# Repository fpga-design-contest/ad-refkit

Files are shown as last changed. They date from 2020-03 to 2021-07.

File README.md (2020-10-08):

# ad-refkit-sample
A sample design of the reference kit for FPGA Design Competition about autonomous driving

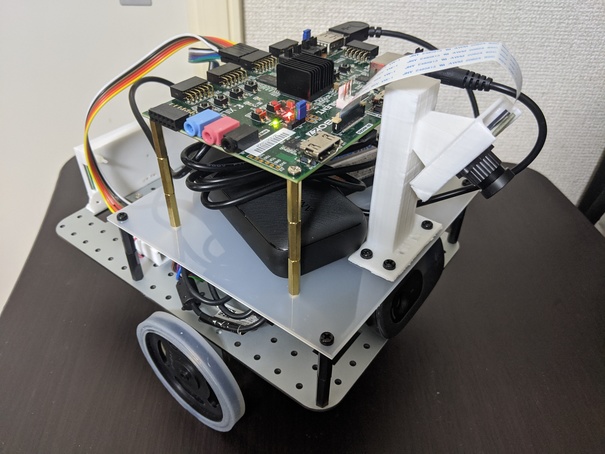
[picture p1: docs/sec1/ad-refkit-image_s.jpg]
ad-refkit


# Setup
See [documentations](./docs/README.md).

# Reference
- Yuya Kudo (Ritsumeikan U.), Atsushi Takada (Ritsumeikan U.), Yuta Ishida (Ritsumeikan U.), and Tomonori Izumi (Ritsumeikan U.), "An SoC-FPGA-Based Micro UGV with Localization and Motion Planning", Proc. 2019 International Conference on Field-Programmable Technology, pp.469-472, DOI 10.1109/ICFPT47387.2019.00095, Dec.2019.
- Yuya Kudo, Atsushi Takada, Soji Tsuda, Takumi Sakai, Tomonori Izumi, "A Platform on All-Programmable SoC for Micro Autonomous Robots", Proc. 2018 International Conference on Field-Programmable Technology, pp.406-409, DOI 10.1109/FPT.2018.00085, Dec.2018.

# Contest
http://fpt19.tju.edu.cn/Contest/FPT2019_FPGA_Design_Competition.htm

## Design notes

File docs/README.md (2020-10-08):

# ad-refkit

1. [Refkit Body](./sec1/index.md)
1. [Building Hardware Design](./sec2/index.md)
1. [Building Linux](./sec3/index.md) optional, prebuilt files are available.
1. [Prepare microSD](./sec4/index.md)
1. [Run Application](./sec5/index.md)

ad-refkit
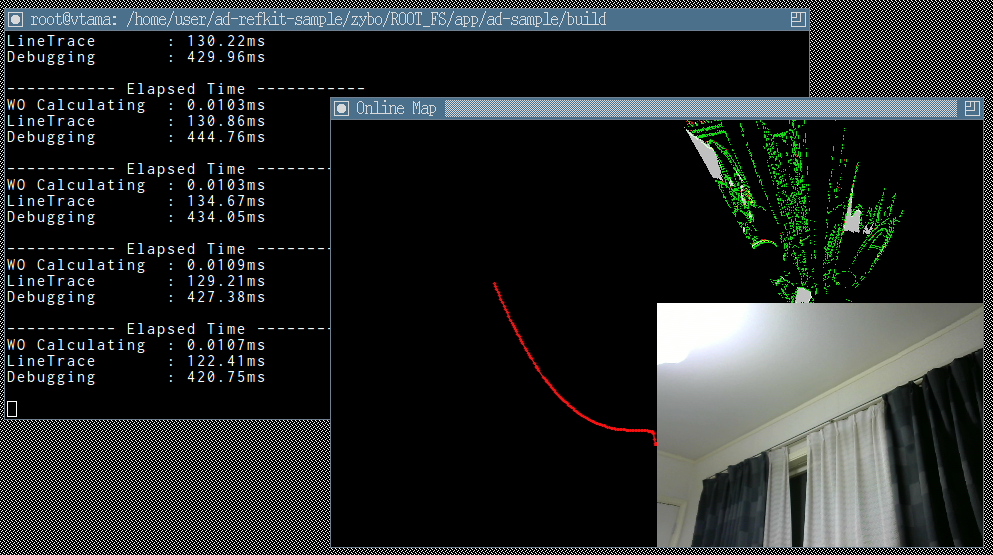
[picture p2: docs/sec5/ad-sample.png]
ad-refkit ad-sample


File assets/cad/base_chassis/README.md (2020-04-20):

# base chassis

ref. http://www.ritsumei.ac.jp/se/re/izumilab/lecture/16zybot/zybotr_base.pdf

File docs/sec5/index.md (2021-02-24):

## Run application
Connect ZYBO Z7-20 and host computer with Ethernet cable and USB cable.\
And then, insert microSD card into ZYBO Z7-20 and turn on the power switch.\
Access to ZYBO Z7-20 via USB tty and assign a IP-address to eth0.

### Setup
Set IP-address on ZYBO Z7-20:

``` sh
# ip addr add <IP ADDRESS> dev eth0 # ex. ip addr add 192.168.2.100/24 dev eth0
```

After that, transfer all of the files in `zybo/ROOT_FS` into `/root` on ZYBO Z7-20.

``` sh
$ scp -r <ROOT OF THIS REPOSITORY>/zybo/ROOT_FS/* root@<IP ADDRESS>:/root
```

### Login and setup kernel-modules and headers

Login to Z7-20 as root by SSH.

``` sh
$ ssh -X root@<IP ADDRESS>
```

In case that your ZYBO Z7-20 cannot connect the Internet, set date by your hand.

```
# date -s "10 JUL 2020 19:40:00" # an example
```

At your first login, run the following commands to install Debian packages.

``` sh
$ cd ~/package
$ dpkg -i linux-image-4.19.0-xilinx_4.19.0-xilinx-4_armhf.deb
$ dpkg -i linux-headers-4.19.0-xilinx_4.19.0-xilinx-4_armhf.deb
$ dpkg -i linux-libc-dev_4.19.0-xilinx-4_armhf.deb
```

### Setup WiFi (if necessary)

Compile the driver on ZYBO Z7-20:

```
# cd /root/rtl8188eu
# git checkout v5.2.2.4
# make
# make install
```

After building and installation of the driver, the dirver module will be loaded at the WiFi adapter connected as the following.

```
# lsmod 
Module                  Size  Used by
8188eu               1392640  0
v4l2                   32768  0
sha256_generic         20480  0
cfg80211              249856  1 8188eu
```

You can find your adapter by `iwconfig`.

```
# iwconfig 
eth0      no wireless extensions.

lo        no wireless extensions.

sit0      no wireless extensions.

wlxd037451c9c81  IEEE 802.11  ESSID:off/any  
          Mode:Managed  Access Point: Not-Associated   Tx-Power=12 dBm   
          Retry short limit:7   RTS thr:off   Fragment thr:off
          Encryption key:off
          Power Management:on
```

You can make a setup of WiFi connection by the following instructions.

1. Generate `wpa_supplicant.conf` (only first time to connect the target SSID)

```
# wpa_passphrase <YOUR SSID> <YOUR PASSWORD> > /etc/wpa_supplicant/wpa_supplicant.conf
```

2. Add some parameters in `/etc/wpa_supplicant/wpa_supplicant.conf` (only first time to connect the target SSID)

```
        proto=RSN
        key_mgmt=WPA-PSK
        pairwise=CCMP
        group=CCMP
```

3. Connect WiFi access point and get IP-address

```
# wpa_supplicant -iwlxd037451c9c81 -c/etc/wpa_supplicant/wpa_supplicant.conf &
# dhclient wlxd037451c9c81
```

The WiFi modules work well are Buffalo WLI-UC-GNM, PLANEX GW-USValue-EZ, TP-Link TL-WN725N, and Elecom WDC-150SU2MBK.

### Before running applictions

Execute `init.sh`.
Executing this script is necessary every time before running ad-refkit applications.

``` sh
$ sh init.sh
```
For Experimantal Vivado 2020.1 support, please execute init20201.sh instead.

### ad-sample

``` sh
$ cd <ROOT OF THIS REPOSITORY>/zybo/ROOT_FS/app/ad-sample
$ export AD_SAMPLE_ROOT=$(pwd)
$ mkdir build && cd build
$ cmake ..
$ make
$ ./ad-sample
```

ad-sample

(sorry, this example picture is case not running on the course)

### make-calibration-param
(You should see in this process in [ad-refkit calibration](https://docs.google.com/presentation/d/18L2UL7cB7N1HqGs9Y_z4J0kfmSX4V-YpADnjRLmr1OU/edit#slide=id.p) (sorry written in Japanese))

Execute camera calibration by using OpenCV.
First of all, make `take-pcam-image` as the following.

``` sh
$ cd <ROOT OF THIS REPOSITORY>/zybo/ROOT_FS/app/take-pcam-image
$ mkdir build && cd build
$ cmake ..
$ make
```

And then, prepare image data by the following processes.

1. Print checkerboard (available on http://opencv.jp/sample/pics/chesspattern_7x10.pdf)
2. Take about 30 pictures of the checkerboard from various angles by using the calibration target camera with built `take-pcam-image`.
    - Take pictures of whole of checkerboard.
    - Save pictures in a directory.
    - The extension of the files should be png (as the application default).
    - The name of the files should be `img<#>.png` (as the application default).
    - `<#>` should be series numbers from `0` (as the application default).

After preparing picture files, start calibration.

``` sh
$ cd <ROOT OF THIS REPOSITORY>/zybo/ROOT_FS/app/make-calibration-param
$ mkdir build && cd build
$ cmake ..
$ make
$ ./make-calibration-param
```

The `make-calibration-param` execution should be like the following.

```
$ cd app/take-pcam-image
$ mkdir build
$ cmake ..
$ make
$ ./make-calibration-param 
Please input a path where you saved checkerboard images : ../data/
Please input the number of image : 30
Please input the number of checker board column : 10
Please input the number of checker board row : 7
Please input squares size (mm) : 23
…
```

The program displays pictures, enter some key to progress the operation.

After executing the program, you can get `calib_param.xml` in the directory. You should copy the generated `calib_param.xml` into apropreate directries.

```
$ cp calib_param.xml ../../pcam-test/data/pcam_calibration_parameter.xml
$ cp calib_param.xml ../../ad-sample/data/HWController/pcam_calibration_parameter.xml
```

### make-homography-param
(You should see in this process in [ad-refkit calibration](https://docs.google.com/presentation/d/18L2UL7cB7N1HqGs9Y_z4J0kfmSX4V-YpADnjRLmr1OU/edit#slide=id.p) (sorry written in Japanese))

Calculate the projection transformation matrix required to obtain a bird's eye view
of the road surface in front of car.
First of all, prepare image data by the follow steps.

1. Prepare a square of paper or a thin board
2. Place the prepared paper or a thin board on the floor in front of the front of the vehicle.
3. Take a picture of the paper or the board by using `take-pcam-image`

After preparing image data, run the follow program.

``` sh
$ python3 make-homography-param.py
```

The program should be execucted as below.

```
$ cd app/make-homography-param
$ python3 make-homography-param.py 
Please input a corrected image path from Pcam5C that has not been transformed.
Note that an image should be included a square pattern on the ground.
>> img2-0.png
Click on the square vertices in the image in the order shown below:
1. Top Left
2. Bottom Left
3. Top Right
4. Bottom Right
(385, 379)
(280, 638)
(790, 376)
(883, 634)
Please choose menu shown below:
'c': Specify ratio and Y-axis offset
'q': Quit and Show the homography matrix
```

Click on the corners of the square and specify the magnification and offset to output the projection transformation matrix.

```
Homography Matrix:
[ 0.154904608011 , -0.075484258313 , 62.9015488835 
 -0.00132486853534 , 0.0190262314547 , 104.989571058 
 -4.64648773206e-07 , -0.000125816562256 , 0.276168644843 ]
```

Copy the output matrix into `app/ad-sample/data/HWController/param.yaml` and `app/pcam-test/src/main.cpp`

### motor-test
This program checks the behavior of motors.

``` sh
$ cd <ROOT OF THIS REPOSITORY>/zybo/ROOT_FS/app/motor-test
$ mkdir build && cd build
$ cmake ..
$ make
$ ./motor-test
```

### pcam-test
This program checks the behavior of Pcam5C.

``` sh
$ cd <ROOT OF THIS REPOSITORY>/zybo/ROOT_FS/app/pcam-test
$ mkdir build && cd build
$ cmake ..
$ make
$ ./pcam-test
```

### webcam-test
This program checks the behavior of Web camera working.

``` sh
$ cd <ROOT OF THIS REPOSITORY>/zybo/ROOT_FS/app/webcam-test
$ mkdir build && cd build
$ cmake ..
$ make
$ ./webcam-test
```

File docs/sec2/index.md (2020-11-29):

# Hardware Design
This flow generates a sample IP-block, bit-stream for ZYBO Z7-20, and BSP for the generated HW.

## Requirements
- Host PC, installed Ubuntu 18.04
- Vivado 2019.1
- [Digilent board files](https://github.com/Digilent/vivado-boards)
- A license for MIPI CSI controller from [MIPI CSI Controller Subsystems](https://www.xilinx.com/products/intellectual-property/ef-di-mipi-csi-rx.html) This license is already included in your Vivado license if you obtained your Webpack license from January 2020, the following step might be required if you have the older Webpack license:
  - Access to [Product Licensing](http://www.xilinx.com/getlicense)
  - Click "Search Now"
  - Type "MIPI CSI" in "Search:" text field
  - Select "LogiCORE, MIPI CSI-2 Rx Controller, Evaluation License" and Click "Add" button
  - Find "LogiCORE, MIPI CSI-2 Rx Controller, Evaluation License", click checkbox of that, and click "Generate Node-Locked License"
  - Fill required license and you can get an evaluation license of MIPI CSI controller.

## Build Flow
Run the following script to generate hardware design. Make sure Vivado is in your path by sourcing the `settings64.sh` in Vivado's directory. 

``` sh
$ cd <ROOT OF THIS REPOSITORY>/zybo/vivado/script
$ export AD_REFKIT_SAMPLE_SCRIPT_PATH=$(pwd)
$ sh setup_bd.sh
```

The script starts Vivado HLS and Vivado to generate IP-block and bit-file. The working directory is `$AD_REFKIT_SAMPLE_SCRIPT_PATH/../prj` .
After running Vivado, the script generates `fpga.bin` in `<ROOT OF THIS REPOSITORY>/ROOT_FS/firmware`, which is a configuration file for dynamic reconfiguration of ZYBO Z7-20. Please follow the board manual on how to program the FPGA using the generated bit file.
The script also generates BSP for software development in `<ROOT OF THIS REPOSITORY>/zybo/ROOT_FS/zynq_bsp/`.

## Experimental Build Flow with Vivado 2020.1
Starting from Vivado 2020.1, the Xilinx XSDK is replaced with a new development platform called Vitis. The Vitis API is different compared to the old XSDK. Also, the MIPI CSI IP which is used in this project is updated. Therefore, we provide a different build script for Vivado 2020.1 platform. Once the project is initiated for Vivado 2020.1, it will not be able to be opened in older Vivado version.
The bit stream format of 2020.1 version also changes as the fpga-bit2bin.py script can no longer convert the bitstream into a proper bin file. The included bootgen from vivado does the trick. However, this change also requires a lot of other changes on the subsequent software build process as the new bin format cannot be recognized by the fpga_manager built into old Xilinx kernel. Newer format requires newer kernel from Xilinx repository and upgrading Linux kernel requires adjustment on the drivers and a lot of other things.
This build flow is experimantal and seems to be sensitive to the gcc version installed in the host PC among other things. Please run the following script if you would like to try.

``` sh
$ cd <ROOT OF THIS REPOSITORY>/zybo/vivado/script
$ export AD_REFKIT_SAMPLE_SCRIPT_PATH=$(pwd)
$ sh setup_bd_20201.sh
```

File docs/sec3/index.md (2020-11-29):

## Building Linux
This step is optional. The generated files by this flow are available in this repository.
The required files are as follows:
- [uImage](../../zybo/BOOT_FS/uImage)
- [zynq-zybo-z7.dtb](../../zybo/BOOT_FS/zynq-zybo-z7.dtb)
- [Debian packages (headers, image, libc)](../../zybo/ROOT_FS/package/)

If you want to build the Linux kernel on your computer, please run the followings:
``` sh
$ apt install build-essential ccache bc bison flex ncurses-dev git u-boot-tools gcc-arm*
$ git clone --depth 1 -b xilinx-v2019.1 https://github.com/Xilinx/linux-xlnx.git linux-xlnx-v2019.1-zybo-z7 && cd linux-xlnx-v2019.1-zybo-z7
$ git checkout -b linux-xlnx-v2019.1-zybo-z7 refs/tags/xilinx-v2019.1
$ sed -i -e 's|bootargs = ""|bootargs = "console=ttyPS0,115200 root=/dev/mmcblk0p2 rw earlyprintk rootfstype=ext4 rootwait devtmpfs.mount=1 uio_pdrv_genirq.of_id=generic-uio earlycon"|g' arch/arm/boot/dts/zynq-zybo-z7.dts
$ patch -p1 < <ROOT OF THIS REPOSITORY>/assets/patch/linux-xlnx-v2019.1-zybo-z7-builddeb.diff
$ git add --update
$ git commit -m "update dts for zybo-z7"
$ git tag -a xilinx-v2019.1-zybo-z7-3 -m "release xilinx-v2019.1-zybo-z7-3"
$ echo 3 > .version
$ make xilinx_zynq_defconfig ARCH=arm CROSS_COMPILE=arm-linux-gnueabihf-
$ patch -p0 < <ROOT OF THIS REPOSITORY>/assets/patch/dot.config.patch
$ ccache make -j<some number> deb-pkg ARCH=arm CROSS_COMPILE=arm-linux-gnueabihf- DTC_FLAGS=--symbols
$ make uImage ARCH=arm CROSS_COMPILE=arm-linux-gnueabihf- UIMAGE_LOADADDR=0x8000
$ cp arch/arm/boot/uImage <ROOT OF THIS REPOSITORY>/zybo/BOOT_FS
$ cp arch/arm/boot/dts/zynq-zybo-z7.dtb <ROOT OF THIS REPOSITORY>/zybo/BOOT_FS
$ cp ../linux-*.deb <ROOT OF THIS REPOSITORY>/zybo/ROOT_FS/package
```
A shell script to automate this process is provided for your convenience. Install the requirements then run the provided script. Make sure `AD_REFKIT_SAMPLE_SCRIPT_PATH` is set as instructed in the previous step.
``` sh
$ sudo apt install build-essential ccache bc bison flex ncurses-dev git u-boot-tools gcc-arm*
$ sh build_linux.sh
```
For the experimental Vivado 2020.1 support, you can skip this process as the Linux build process is integrated into the ROOT FS build flow.

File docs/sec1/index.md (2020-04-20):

## ad-refkit body

ad-refkit

### Requirements

| Item | Qty. | Vendor | Remark |
|---|:----:|:---:|---|
| ZYBO Z7-20 | 1 | Digilent | https://store.digilentinc.com/zybo-z7-zynq-7000-arm-fpga-soc-development-board/ |
| Motor | 2 | Digilent | https://store.digilentinc.com/dc-motor-gearbox-1-53-gear-ratio-custom-6v-motor-designed-for-digilent-robot-kits/ |
| Tire and Wheel | 2 | Digilent | https://store.digilentinc.com/wheel-kit-d-slot-pair-abs-injection-molded-wheels-compatible-with-digilent-motor-mounts-limited-time/ |
| Tail Skid | 1 | Digilent | https://store.digilentinc.com/tail-skid-limited-time/ |
| Pcam5C | 1 | Digilent | https://reference.digilentinc.com/reference/add-ons/pcam-5c/start |
| Pmod HB5 | 2 | Digilent | https://store.digilentinc.com/pmod-hb5-h-bridge-driver-with-feedback-inputs/ |
| Motor mounter | 1 | Digilent | https://store.digilentinc.com/double-motor-mount-metal-mount-to-affix-a-pair-of-digilent-motors-limited-time/ |
| Mobile Battery (PowerCore 10000 PD Redux) | 1 | Anker | https://www.ankerjapan.com/category/COMPACT/A1239.html |
| Web camera | 1 | | |
|  - ex. BSW20KM11BK | | iBUFFALO | https://www.buffalo.jp/product/series/BSW20KM11BK |
|  - ex. Logicool C270 | | Logicool | https://www.logitech.com/en-us/product/hd-webcam-c270 |
| USB Hub | 1 | | https://www.sanwa.co.jp/product/syohin.asp?code=USB-HTV410BKN |
|  - ex. USB-HTV410BKN | | SANWASUPPLY | https://www.sanwa.co.jp/product/syohin.asp?code=USB-HTV410BKN |
|  - ex. U2H-TZ427SBK | | Elecom | https://www.elecom.co.jp/products/U2H-TZ427SBK.html |
| Debug console (character display) | 1 | | |
|  - ex. Kyoritsu OLED display module | | KYOHRITSU | https://eleshop.jp/shop/g/gC9B362/ |
|  - ex. Akizuki OLED display module | | Akizuki | http://akizukidenshi.com/catalog/g/gP-08277/ |
| micro SD | 1 | - | more than 8GB |
| USB Type-A to DC-jack | 1 | | |
|  - ex. BENSN 10 in 1 | | | https://www.amazon.co.jp/gp/product/B07Y5DCBRL/ |
| Battery holder for 4xAAA | 1 | | |
| Base chassis | 1 | - | [STEP](../../assets/cad/base_chassis/robocar_base2.step) |
| Middle layer chassis | 1 | - | |
| Pcam5C mounter | 1 | - | [STL](../../assets/cad/Pcam5C/Pcam5C_mounter.stl) |
| OLED holder | 1 | - | [STL](../../assets/cad/OLED_holder/OLED_holder.stl) |
| HB5 holder | 2 | - | [STL](../../assets/cad/HB5_holder/HB5_holder.stl) |
| spacers, screws, nuts, washers | | | |
| wires | | | |
| Self Adhesive magnetic tape | | | |

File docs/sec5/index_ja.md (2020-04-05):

## アプリケーションの実行
イーサネットケーブルを用意し、ZYBOのイーサネットポートに差し込みます。\
ケーブルをホストPCと同一セグメントに存在するDHCP機能を持つルータに接続した後、
作成したMicroSDカードをZYBO Z7-20にセットし、電源を投入してください。\
UARTのシリアルコンソールからログインし、DHCPにより割り振られたIPアドレスを確認します。

``` sh
$ ip address show
```

IPアドレスが確認出来たら、
`zybo/ROOT_FS`下のすべてのファイルをZYBOで動作するUbuntu上の`/root`下に転送してください。

``` sh
$ scp -r <ROOT OF THIS REPOSITORY>/zybo/ROOT_FS/* root@<ZYBOのIPアドレス>:/root
```

SSHでrootログインします。

``` sh
$ ssh -X root@<ZYBOのIPアドレス>
```

最初の一度だけパッケージのインストールを行う必要があります。

``` sh
$ cd ~/package
$ dpkg -i linux-image-4.19.0-xilinx_4.19.0-xilinx-4_armhf.deb
$ dpkg -i linux-headers-4.19.0-xilinx_4.19.0-xilinx-4_armhf.deb
$ dpkg -i linux-libc-dev_4.19.0-xilinx-4_armhf.deb
```

次に`init.sh`を実行して下さい。
これは**ZYBOを起動する度**に実行する必要があります。

``` sh
$ sh init.sh
```

以上でアプリケーションの実行が可能になります。

### ad-sample
NOTE: 動作未確認

``` sh
$ cd <ROOT OF THIS REPOSITORY>/zybo/ROOT_FS/app/ad-sample
$ export AD_SAMPLE_ROOT=$(pwd)
$ mkdir build && cd build
$ cmake ..
$ make
$ ./ad-sample
```

### make-calibration-param
NOTE: 動作未確認

OpenCVを用いたカメラキャリブレーションを実行します。\
はじめに、以下の手順に従って画像データを用意して下さい。

1. チェッカーボードを印刷する
2. キャリブレーションを行うカメラでチェッカーボードを様々な角度から30枚程度撮影する
    - チェッカーボード全体が映るように撮影してください
    - 画像ファイルは同一ディレクトリ下に保存してください
    - png形式で保存して下さい
    - ファイル名は`img<番号>.png`としてください
    - `<番号>`は`0`から始まる連番にしてください

画像データが用意できたらキャリブレーションを実行します。

``` sh
$ cd <ROOT OF THIS REPOSITORY>/zybo/ROOT_FS/app/make-calibration-param
$ mkdir build && cd build
$ cmake ..
$ make
$ ./make-calibration-param
```

### make-homography-param
前方の路面の俯瞰画像を得る際に必要な射影変換行列を導出します。\
はじめに、以下の手順に従って画像データを用意して下さい。

1. 正方形の紙、もしくは、薄い板を用意する
2. 用意した紙、もしくは、薄い板を車体の前方正面の床面に設置する
3. 撮影する

画像データが用意できたらプログラムを実行します。

``` sh
$ python3 make-homography-param.py
```

正方形の四隅をクリックし、倍率、オフセットを指定すると射影変換行列が出力されます。

### motor-test
モータの動作を確認することが出来ます。

``` sh
$ cd <ROOT OF THIS REPOSITORY>/zybo/ROOT_FS/app/motor-test
$ mkdir build && cd build
$ cmake ..
$ make
$ ./motor-test
```

### pcam-test
NOTE: 動作未確認

``` sh
$ cd <ROOT OF THIS REPOSITORY>/zybo/ROOT_FS/app/pcam-test
$ mkdir build && cd build
$ cmake ..
$ make
$ ./pcam-test
```

### webcam-test
NOTE: 動作未確認

``` sh
$ cd <ROOT OF THIS REPOSITORY>/zybo/ROOT_FS/app/webcam-test
$ mkdir build && cd build
$ cmake ..
$ make
$ ./webcam-test
```

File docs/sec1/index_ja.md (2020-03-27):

## 車体の構築
TODO: 車体のディテールを固める

### 必要な部品

| 名称 | 数量 | メーカー | 備考 |
|---|:----:|:---:|---|
| ZYBO Z7-20 | 1 | Digilent | https://store.digilentinc.com/zybo-z7-zynq-7000-arm-fpga-soc-development-board/ |
| モーター | 2 | Digilent | https://store.digilentinc.com/dc-motor-gearbox-1-53-gear-ratio-custom-6v-motor-designed-for-digilent-robot-kits/ |
| 車輪 | 2 | Digilent | https://store.digilentinc.com/wheel-kit-d-slot-pair-abs-injection-molded-wheels-compatible-with-digilent-motor-mounts-limited-time/ |
| タイヤ | 2 | Digilent | https://store.digilentinc.com/wheel-kit-d-slot-pair-abs-injection-molded-wheels-compatible-with-digilent-motor-mounts-limited-time/ |
| キャスター | 1 | Digilent | https://store.digilentinc.com/tail-skid-limited-time/ |
| モバイルバッテリー(PowerCore+ 26800 PD) | 1 | Anker | https://www.ankerjapan.com/item/B1375.html |
| Pcam | 1 | Digilent | https://reference.digilentinc.com/reference/add-ons/pcam-5c/start |
| Webカメラ(BSW20KM11BK) | 1 | iBUFFALO | https://www.buffalo.jp/product/series/BSW20KM11BK |
| USBハブ | 1 | SANWASUPPLY | https://www.sanwa.co.jp/product/syohin.asp?code=USB-HTV410BKN |
| Pmod HB5 | 2 | Digilent | https://store.digilentinc.com/pmod-hb5-h-bridge-driver-with-feedback-inputs/ |
| 車輪モータマウント | 1 | Digilent | https://store.digilentinc.com/double-motor-mount-metal-mount-to-affix-a-pair-of-digilent-motors-limited-time/ |
| OLEDディスプレイモジュール | 1 | KYOHRITSU | https://eleshop.jp/shop/g/gC9B362/ |
| micro SD | 1 | - | 8GB以上推奨 |
| プラスチック板 | 2 | - | - |
| スペーサー 3cm | 2 | - | - |
| スペーサー 5cm | 2 | - | - |
| スペーサー 6cm | 4 | - | - |
| ネジ | - | - | - |
| ワッシャー | - | - | - |
| ナット | - | - | - |
| USB typeA to DCプラグ | 2 | - | ZYBO給電用とUSBハブ給電用 外径3.5mm |

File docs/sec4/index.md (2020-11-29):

## Prepare microSD
### 1. Format the MicroSD Card
Make partition with GParted. \
If you do not have GParted installed yet, please install it. Also, debootstrap is required to create a basic debian filesystem on the MicroSD.

``` sh
$ sudo apt install gparted debootstrap 
```

Run GParted, and then make two partitions on the MicroSD as follows:

``` sh
$ sudo gparted
```

- 1st partition : fat16, about 64-128MiB
- 2nd partition : ext4, all of rest

Pay attention to your MicroSD location (`/dev/sdX`) with X denoting your MicroSD location. Be careful not to use another drive.

### 2. Prepare rootfs
The next step is building the debian root filesystem for the FPGA board. There are two ways to achieve this: building the entire filesystem on host PC, then copy the resulting files to the MicroSD, or mount the MicroSD and build the filesystem directly on the MicroSD. The latter is considerably slower than the former. As a third option, we can use the provided script to streamline the building process for your convenience.

To achieve this, we will create a new chroot-ed directory for the debootstrap to work, then set the architecture of the filesystem to ARM. QEMU will be used to run the chroot-ed ARM filesystem on your PC. As the debootstrap completes its task, we will then install and configure the system as well as compiling OpenCV. The OpenCV compilation might take few hours depending on your PC. 

#### Building rootfs directly on the MicroSD

```
# install Ubuntu 18.04 LTS and neessary packages
$ sudo mount /dev/<YOUR SD #2 partition> /mnt # ex. /dev/sdd2
$ sudo debootstrap --foreign --arch armhf bionic /mnt http://ports.ubuntu.com/
$ sudo apt install qemu-user-static
$ sudo cp /usr/bin/qemu-arm-static /mnt/usr/bin/
$ sudo chroot /mnt
I have no name!@ubuntu:# ./debootstrap/debootstrap --second-stage
I have no name!@ubuntu:# passwd
I have no name!@ubuntu:# su
root@ubuntu:# passwd
root@ubuntu:# apt install software-properties-common
root@ubuntu:# add-apt-repository universe && apt update
root@ubuntu:# adduser user
root@ubuntu:# apt install locales ssh chrony libusb-1.0-0-dev
root@ubuntu:# locale-gen en_US.UTF-8
root@ubuntu:# apt install git
root@ubuntu:# git clone -b v1.4.7 https://git.kernel.org/pub/scm/utils/dtc/dtc.git dtc && cd dtc
root@ubuntu:# apt install build-essential flex bison
root@ubuntu:# make && make HOME=/usr install-bin
root@ubuntu:# cd .. && rm -rf dtc
root@ubuntu:# sed -i -e 's/#PasswordAuthentication/PasswordAuthentication/g' /etc/ssh/sshd_config
root@ubuntu:# sed -i -e 's/#PermitRootLogin prohibit-password/PermitRootLogin yes/g' /etc/ssh/sshd_config
root@ubuntu:# sed -i -e 's/AcceptEnv/#AcceptEnv/g' /etc/ssh/sshd_config
root@ubuntu:# echo 'server <available NTP server> iburst' >> /etc/ntp.conf # For example, ntp1.jst.mfeed.ad.jp
root@ubuntu:# systemctl enable chrony
root@ubuntu:# cat <<EOT > /etc/systemd/network/eth0.network
              [Match]
              Name=eth0
              [Network]
              DHCP=ipv4
              EOT
root@ubuntu:# systemctl enable systemd-networkd

# install OpenCV 4.2.0
root@ubuntu:# apt install -y \
              build-essential cmake ccache git pkg-config libgtk-3-dev \
              libavcodec-dev libavformat-dev libswscale-dev libv4l-dev \
              libxvidcore-dev libx264-dev libjpeg-dev libpng-dev libtiff-dev \
              gfortran openexr libatlas-base-dev python3-dev python3-numpy \
              libtbb2 libtbb-dev libdc1394-22-dev
root@ubuntu:# mkdir opencv_build && cd opencv_build
root@ubuntu:# git clone --depth 1 https://github.com/opencv/opencv.git
root@ubuntu:# git clone --depth 1 https://github.com/opencv/opencv_contrib.git
root@ubuntu:# export OPENCV_BUILD_PATH=$(pwd)
root@ubuntu:# cd opencv && mkdir build && cd build
root@ubuntu:# cmake -D CMAKE_BUILD_TYPE=RELEASE \
                    -D CMAKE_INSTALL_PREFIX=/usr/local \
                    -D INSTALL_C_EXAMPLES=ON \
                    -D INSTALL_PYTHON_EXAMPLES=ON \
                    -D OPENCV_GENERATE_PKGCONFIG=ON \
                    -D OPENCV_EXTRA_MODULES_PATH=$(printenv OPENCV_BUILD_PATH)/opencv_contrib/modules \
                    -D BUILD_EXAMPLES=ON ..
root@ubuntu:# ccache make -j<some number> # 4-5 hours, depends on your environment
root@ubuntu:# make install
root@ubuntu:# pkg-config --modversion opencv4
root@ubuntu:# cd ../../../ && rm -rf opencv_build
root@ubuntu:# apt install -y wireless-tools rfkill wpasupplicant linux-firmware libssl-dev usbutils
root@ubuntu:# cd /root
root@ubuntu:# git clone https://github.com/lwfinger/rtl8188eu.git
root@ubuntu:# exit
I have no name!@ubuntu:# exit
$ sync; sync; sync
$ sudo umount /mnt
$ sudo eject /dev/<YOUR SD> /mnt # ex. /dev/sdd
```

#### Building rootfs on your host PC and copy the files to MicroSD

```
$ mkdir <WORKING DIRECTORY>; cd <WORKING DIRECTORY> # ~/microsd
$ export WORKDIR=$(pwd)
$ sudo debootstrap --foreign --arch armhf bionic $WORKDIR http://ports.ubuntu.com/ 
$ sudo apt install qemu-user-static
$ sudo cp /usr/bin/qemu-arm-static $WORKDIR/usr/bin/
$ sudo chroot $WORKDIR
I have no name!@ubuntu:# ./debootstrap/debootstrap --second-stage
I have no name!@ubuntu:# passwd
I have no name!@ubuntu:# su
root@ubuntu:# passwd
root@ubuntu:# apt install -y software-properties-common
root@ubuntu:# add-apt-repository universe && apt update
root@ubuntu:# adduser user
root@ubuntu:# apt install -y locales ssh chrony libusb-1.0-0-dev ntpdate bc
root@ubuntu:# locale-gen en_US.UTF-8
root@ubuntu:# apt install -y git
root@ubuntu:# git clone -b v1.4.7 https://git.kernel.org/pub/scm/utils/dtc/dtc.git dtc && cd dtc
root@ubuntu:# apt install -y build-essential flex bison
root@ubuntu:# make && make HOME=/usr install-bin
root@ubuntu:# cd .. && rm -rf dtc
root@ubuntu:# sed -i -e 's/#PasswordAuthentication/PasswordAuthentication/g' /etc/ssh/sshd_config
root@ubuntu:# sed -i -e 's/#PermitRootLogin prohibit-password/PermitRootLogin yes/g' /etc/ssh/sshd_config
root@ubuntu:# sed -i -e 's/AcceptEnv/#AcceptEnv/g' /etc/ssh/sshd_config
root@ubuntu:# echo 'server <available NTP server> iburst' >> /etc/ntp.conf # For example, ntp1.jst.mfeed.ad.jp
root@ubuntu:# systemctl enable chrony
root@ubuntu:# cat <<EOT > /etc/systemd/network/eth0.network
              [Match]
              Name=eth0
              [Network]
              DHCP=ipv4
              EOT
root@ubuntu:# systemctl enable systemd-networkd

# install OpenCV 4.2.0
root@ubuntu:# apt install -y \
              build-essential cmake ccache git pkg-config libgtk-3-dev \
              libavcodec-dev libavformat-dev libswscale-dev libv4l-dev \
              libxvidcore-dev libx264-dev libjpeg-dev libpng-dev libtiff-dev \
              gfortran openexr libatlas-base-dev python3-dev python3-numpy \
              libtbb2 libtbb-dev libdc1394-22-dev
root@ubuntu:# mkdir opencv_build && cd opencv_build
root@ubuntu:# git clone --depth 1 https://github.com/opencv/opencv.git
root@ubuntu:# git clone --depth 1 https://github.com/opencv/opencv_contrib.git
root@ubuntu:# export OPENCV_BUILD_PATH=$(pwd)
root@ubuntu:# cd opencv && mkdir build && cd build
root@ubuntu:# cmake -D CMAKE_BUILD_TYPE=RELEASE \
                    -D CMAKE_INSTALL_PREFIX=/usr/local \
                    -D INSTALL_C_EXAMPLES=ON \
                    -D INSTALL_PYTHON_EXAMPLES=ON \
                    -D OPENCV_GENERATE_PKGCONFIG=ON \
                    -D OPENCV_EXTRA_MODULES_PATH=$(printenv OPENCV_BUILD_PATH)/opencv_contrib/modules \
                    -D BUILD_EXAMPLES=ON ..
root@ubuntu:# ccache make -j<some number> # 2-3 hours, depends on your environment
root@ubuntu:# make install
root@ubuntu:# pkg-config --modversion opencv4
root@ubuntu:# cd ../../../ && rm -rf opencv_build
root@ubuntu:# apt install -y wireless-tools rfkill wpasupplicant linux-firmware libssl-dev usbutils
root@ubuntu:# cd /root
root@ubuntu:# git clone https://github.com/lwfinger/rtl8188eu.git
root@ubuntu:# exit
I have no name!@ubuntu:# exit
$ sudo mount /dev/<YOUR SD #2 partition> /mnt # ex. /dev/sdd2
$ cd $WORKDIR
$ sudo tar cpvf - * | sudo tar xpvf - -C /mnt
$ sync; sync; sync
$ sudo umount /mnt
$ sudo eject /dev/<YOUR SD> /mnt # ex. /dev/sdd
```

#### Building rootfs on your host PC with the script and  copy the files to MicroSD
Run the following script then copy the generated files to the MicroSD card. The script will generate the MicroSD image on the top most directory of this repository.

```
$ cd <ROOT OF THIS REPOSITORY>/zybo/vivado/script
$ export AD_REFKIT_SAMPLE_SCRIPT_PATH=$(pwd)
$ sh build_rootfs.sh
$ sudo mount /dev/<YOUR SD #2 partition> /mnt # ex. /dev/sdd2
$ cd $WORKDIR
$ sudo tar cpvf - * | sudo tar xpvf - -C /mnt
$ sync; sync; sync
$ sudo umount /mnt
$ sudo eject /dev/<YOUR SD> /mnt # ex. /dev/sdd
```

#### Experimental build flow for Vivado 2020.1
Similar to the last build flow, but instead of calling build_rootfs.sh script, but call build_rootfs20201.sh instead.
```
$ cd <ROOT OF THIS REPOSITORY>/zybo/vivado/script
$ export AD_REFKIT_SAMPLE_SCRIPT_PATH=$(pwd)
$ sh build_rootfs20201.sh
$ sudo mount /dev/<YOUR SD #2 partition> /mnt # ex. /dev/sdd2
$ cd $WORKDIR
$ sudo tar cpvf - * | sudo tar xpvf - -C /mnt
$ sync; sync; sync
$ sudo umount /mnt
$ sudo eject /dev/<YOUR SD> /mnt # ex. /dev/sdd

```
This process will also build the linux kernel and prepare the BOOT FS partition. This experimental build is very sensitive to the gcc version matching between the one installed on the HOST PC and on the ZYBO image among other things. The instalation of kernel driver for the camera, wifi and others on the next section may fail. 
Proceed to copy all the generated files in the BOOT_FS folder into the first partition as described below.

### 3. Prepare bootfs
Copy the following five files into bootfs i.e. 1st partition.

- [BOOT.bin](../../zybo/BOOT_FS/BOOT.bin)
- [uEnv.txt](../../zybo/BOOT_FS/uEnv.txt)
- [uImage](../../zybo/BOOT_FS/uImage)
- [uramdisk.image.gz](../../zybo/BOOT_FS/uramdisk.image.gz)
- [zynq-zybo-z7.dtb](../../zybo/BOOT_FS/zynq-zybo-z7.dtb)

We can use files generated in [Building Linux](../sec3/index.md) or use files in `zybo/BOOT_FS` as they are.

#### 3.1 BOOT.bin
`BOOT.bin` is generated from the follow three files.

- FSBL
- bitstream
- u-boot

These are prepared in `zybo/BOOT_FS/bootbin_src`.\
The details of how to build these files are omitted.\
The prepared bit-stream (`hardware.bit`) just blink LEDs.\
The following commands generates `BOOT.bin`.

``` sh
$ cd <ROOT OF THIS REPOSITORY>/zybo/BOOT_FS/bootbin_src
$ bootgen -arch zynq -image build.bif -w -o ../BOOT.bin
```

#### 3.2 uEnv.txt
``` txt
uenvcmd=fatload mmc 0 0x03000000 uImage && fatload mmc 0 0x02A00000 zynq-zybo-z7.dtb && bootm 0x03000000 - 0x02A00000
ethaddr=02:50:10:70:11:A2
```

#### 3.3 uImage
Use the file generated in [Building Linux](../sec3/index.md)

#### 3.4 uramdisk.image.gz
[Build and Modify a Rootfs](https://xilinx-wiki.atlassian.net/wiki/spaces/A/pages/18842473/Build+and+Modify+a+Rootfs)

#### 3.5 zynq-zybo-z7.dtb
Use the file generated in [Building Linux](../sec3/index.md)

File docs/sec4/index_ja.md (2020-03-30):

## SDカードの準備
### 1. MicroSDカードのフォーマット
GPartedを用いてパーティションの分割・フォーマットを行います。\
インストールされていない場合はパッケージマネージャを用いてインストールしてください。

``` sh
$ sudo apt install gparted
```

GPartedを起動して、MicroSDを指すデバイス指定し、以下のようにパーティションを分けます。

``` sh
$ sudo gparted
```

- 第1パーティション : fat16, 64-128MiB程度
- 第2パーティション : ext4,  残りの全ての領域

### 2. rootfsの用意
以下に示すコマンドを実行して下さい。

```
# install Ubuntu 18.04 LTS and neessary packages
$ sudo mount -o loop /dev/mmcblk0p2 /mnt # /dev/sdd1??
$ sudo debootstrap --foreign --arch armhf bionic /mnt http://ports.ubuntu.com/
$ sudo apt install qemu-user-static
$ sudo cp /usr/bin/qemu-arm-static /mnt/usr/bin/
$ sudo chroot /mnt
I have no name!@ubuntu:# ./debootstrap/debootstrap --second-stage
I have no name!@ubuntu:# passwd
I have no name!@ubuntu:# su
root@ubuntu:# passwd
root@ubuntu:# apt install software-properties-common
root@ubuntu:# add-apt-repository universe && apt update
root@ubuntu:# adduser user
root@ubuntu:# apt install locales ssh chrony libusb-1.0-0-dev
root@ubuntu:# locale-gen en_US.UTF-8
root@ubuntu:# apt install git
root@ubuntu:# git clone -b v1.4.7 https://git.kernel.org/pub/scm/utils/dtc/dtc.git dtc && cd dtc
root@ubuntu:# apt install build-essential
root@ubuntu:# apt install flex bison
root@ubuntu:# make && make HOME=/usr install-bin
root@ubuntu:# cd .. && rm -rf dtc
root@ubuntu:# sed -i -e 's/#PasswordAuthentication/PasswordAuthentication/g' /etc/ssh/sshd_config
root@ubuntu:# sed -i -e 's/#PermitRootLogin prohibit-password/PermitRootLogin yes/g' /etc/ssh/sshd_config
root@ubuntu:# sed -i -e 's/AcceptEnv/#AcceptEnv/g' /etc/ssh/sshd_config
root@ubuntu:# echo 'server <利用可能なNTPサーバ> iburst' >> /etc/ntp.conf # <利用可能なNTPサーバ>の例: ntp1.jst.mfeed.ad.jp
root@ubuntu:# systemctl enable chrony
root@ubuntu:# cat <<EOT > /etc/systemd/network/eth0.network
              [Match]
              Name=eth0
              [Network]
              DHCP=ipv4
              EOT
root@ubuntu:# systemctl enable systemd-networkd

# install OpenCV 4.2.0
root@ubuntu:# apt install -y \
              build-essential cmake ccache git pkg-config libgtk-3-dev \
              libavcodec-dev libavformat-dev libswscale-dev libv4l-dev \
              libxvidcore-dev libx264-dev libjpeg-dev libpng-dev libtiff-dev \
              gfortran openexr libatlas-base-dev python3-dev python3-numpy \
              libtbb2 libtbb-dev libdc1394-22-dev
root@ubuntu:# mkdir opencv_build && cd opencv_build
root@ubuntu:# git clone --depth 1 https://github.com/opencv/opencv.git
root@ubuntu:# git clone --depth 1 https://github.com/opencv/opencv_contrib.git
root@ubuntu:# export OPENCV_BUILD_PATH=$(pwd)
root@ubuntu:# cd opencv && mkdir build && cd build
root@ubuntu:# cmake -D CMAKE_BUILD_TYPE=RELEASE \
                    -D CMAKE_INSTALL_PREFIX=/usr/local \
                    -D INSTALL_C_EXAMPLES=ON \
                    -D INSTALL_PYTHON_EXAMPLES=ON \
                    -D OPENCV_GENERATE_PKGCONFIG=ON \
                    -D OPENCV_EXTRA_MODULES_PATH=$(printenv OPENCV_BUILD_PATH)/opencv_contrib/modules \
                    -D BUILD_EXAMPLES=ON ..
root@ubuntu:# ccache make -j<適当なjob数>
root@ubuntu:# make install
root@ubuntu:# pkg-config --modversion opencv4
root@ubuntu:# cd ../../../ && rm -rf opencv_build

root@ubuntu:# exit
```

### 3. bootfsの用意
以下の5つのファイルをbootfs、つまり、第1パーティションに置きます。

- BOOT.bin
- uEnv.txt
- uImage
- uramdisk.image.gz
- zynq-zybo-z7.dtb

`zybo/BOOT_FS`に用意しているファイルをそのまま利用して問題ありません。

#### 3.1 BOOT.bin
以下に示す3つのファイルを用いて作成します。

- FSBL
- bitstream
- u-boot

これらは`zybo/BOOT_FS/bootbin_src`下に用意しています。\
それぞれのファイルの作成方法は省略します。\
ここに用意しているビットストリームファイル(`hardware.bit`)はLEDを点滅させるだけのものになります。\
`BOOT.bin`は以下のコマンドで生成することが出来ます。

``` sh
$ cd <ROOT OF THIS REPOSITORY>/zybo/BOOT_FS/bootbin_src
$ bootgen -arch zynq -image build.bif -w -o ../BOOT.bin
```

#### 3.2 uEnv.txt
``` txt
uenvcmd=fatload mmc 0 0x03000000 uImage && fatload mmc 0 0x02A00000 zynq-zybo-z7.dtb && bootm 0x03000000 - 0x02A00000
ethaddr=02:50:10:70:11:A2
```

#### 3.3 uImage
`Linuxカーネルのビルド`において作成したものを使用してください。

#### 3.4 uramdisk.image.gz
[Build and Modify a Rootfs](https://xilinx-wiki.atlassian.net/wiki/spaces/A/pages/18842473/Build+and+Modify+a+Rootfs)

#### 3.5 zynq-zybo-z7.dtb
`Linuxカーネルのビルド`において作成したものを使用してください。

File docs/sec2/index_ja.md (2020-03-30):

## Prepare
get mipi-csi controller ip licence from https://japan.xilinx.com/products/intellectual-property/ef-di-mipi-csi-rx.html

## ビットストリームの生成
Block Designを生成するスクリプトを実行します。

``` sh
$ cd <ROOT OF THIS REPOSITORY>/zybo/vivado/script
$ sh setup_bd.sh
```

スクリプトの実行が完了したら、VivadoのGUI上で`Generate Bitstream`を実行して下さい。\
Bitstreamの生成が完了したら、FPGA Regionによる動的読み込みに対応するためにbitファイルをbinファイルに変換します。

``` sh
$ cd <ROOT OF THIS REPOSITORY>/zybo/vivado/script
$ sudo chmod u+x fpga-bit2bin.py
$ sh create_bitstream_bin.sh
```

このスクリプトを実行すると、`zybo/ROOT_FS/firmware`にbinファイルが作成されます。\
次に、以下の手順に従ってXilinx SDKを起動し、BSPを作成してください。

1. [Vivado] File -> Export -> Export Hardware
2. [Vivado] File -> Launch SDK
3. [Xilinx SDK] File -> New -> Board Support Package

`standalone_bsp_0`が作成されたことを確認してください。\
作成されたBSPをコピーします。

``` sh
$ cp -R <ROOT OF THIS REPOSITORY>/zybo/vivado/prj/ad_refkit/ad_refkit.sdk/standalone_bsp_0/ps7_cortexa9_0 \
        <ROOT OF THIS REPOSITORY>/zybo/ROOT_FS/zynq_bsp
```

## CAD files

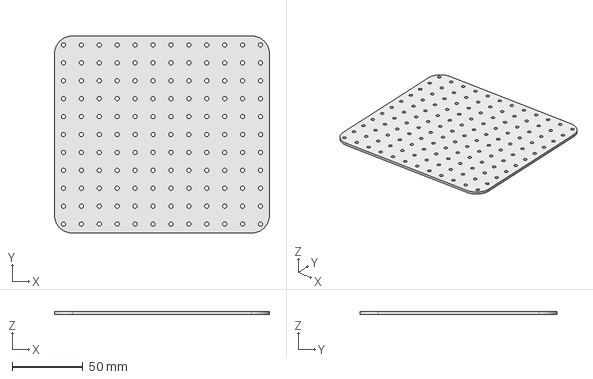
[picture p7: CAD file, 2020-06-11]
assets/cad/base_chassis/robocar_middle.step
152.4 x 139.7 x 2.00 mm

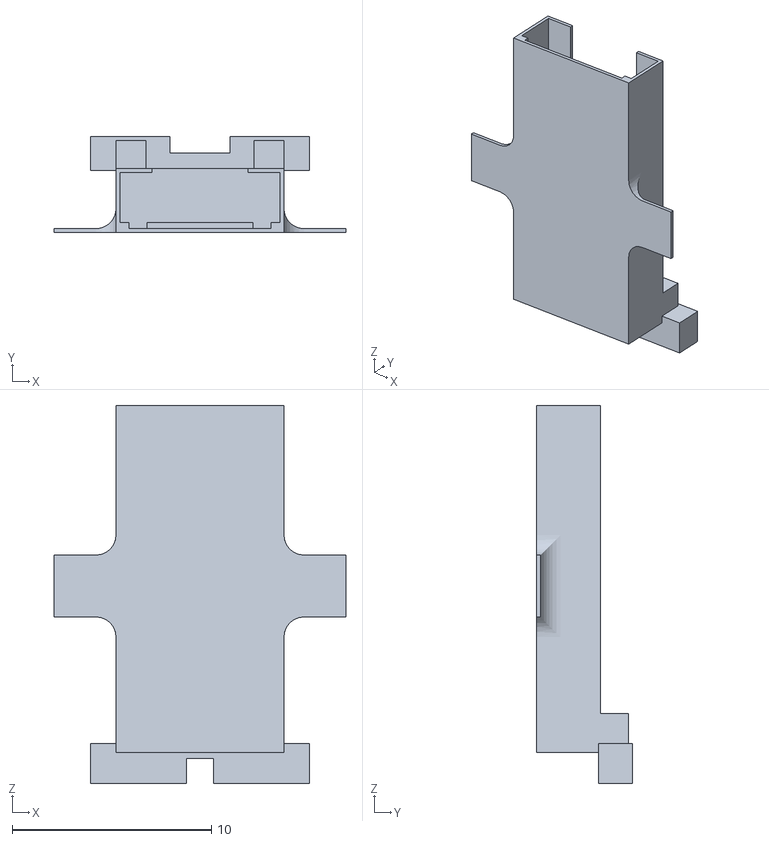
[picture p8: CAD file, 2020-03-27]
assets/cad/battery_case/battery_case.stl
14.6 x 4.82 x 19.0

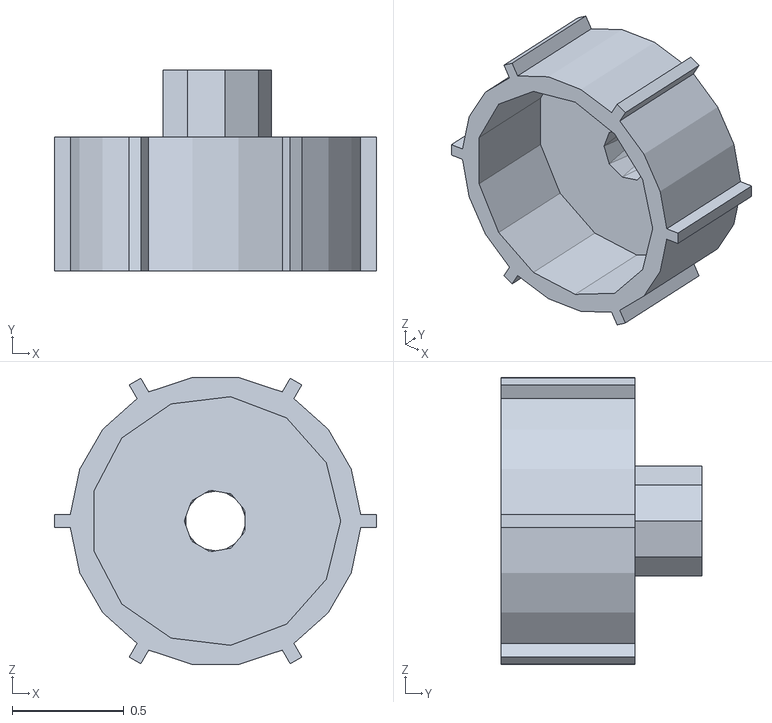
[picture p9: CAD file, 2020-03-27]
assets/cad/camera_cap_holder/camera_cap_holder.stl
1.44 x 0.9 x 1.28

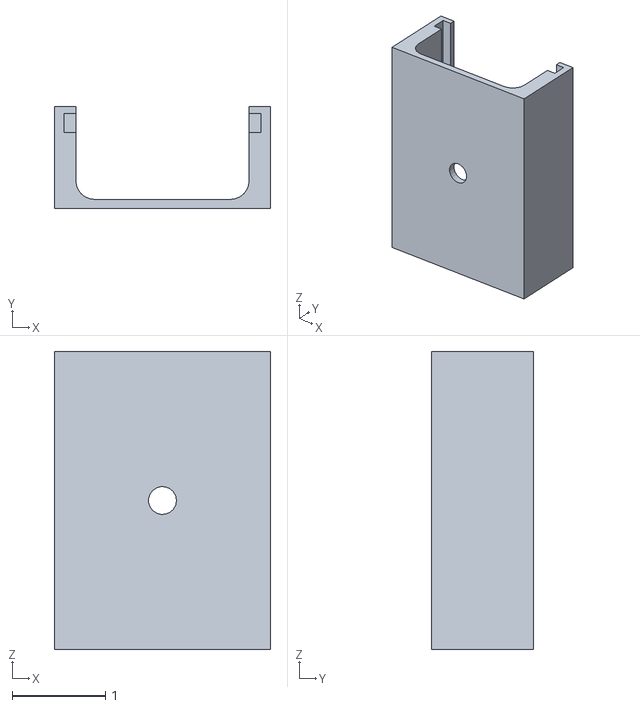
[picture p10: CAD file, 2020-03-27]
assets/cad/HB5_holder/HB5_holder.stl
2.32 x 1.10 x 3.20

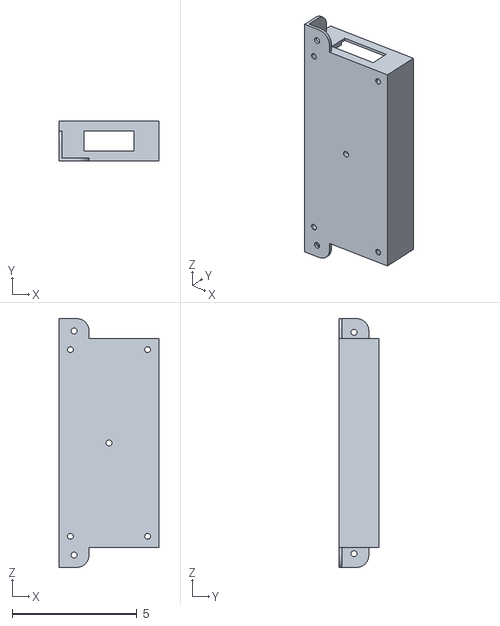
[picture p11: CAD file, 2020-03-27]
assets/cad/OLED_holder/OLED_holder.stl
4.00 x 1.60 x 10.0

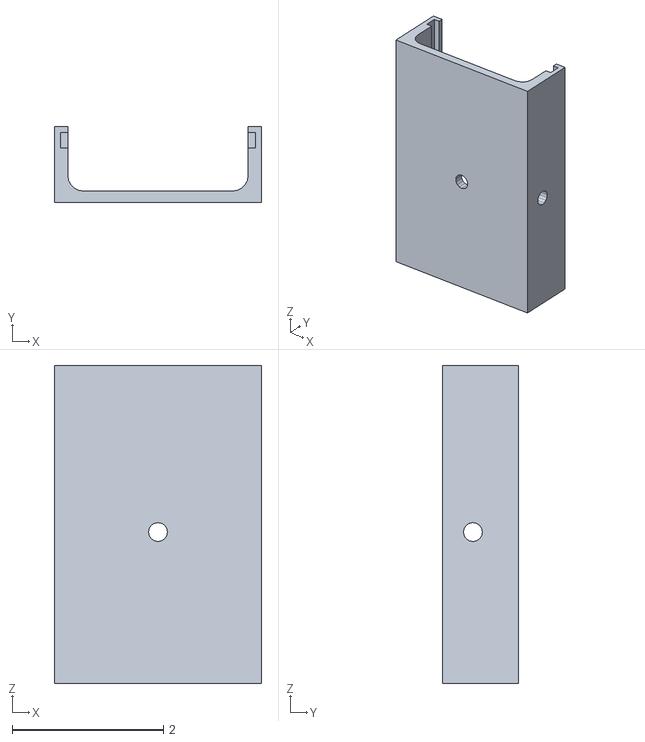
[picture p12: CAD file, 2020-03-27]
assets/cad/Pcam5C/Pcam5C_holder.stl
2.74 x 1.00 x 4.20

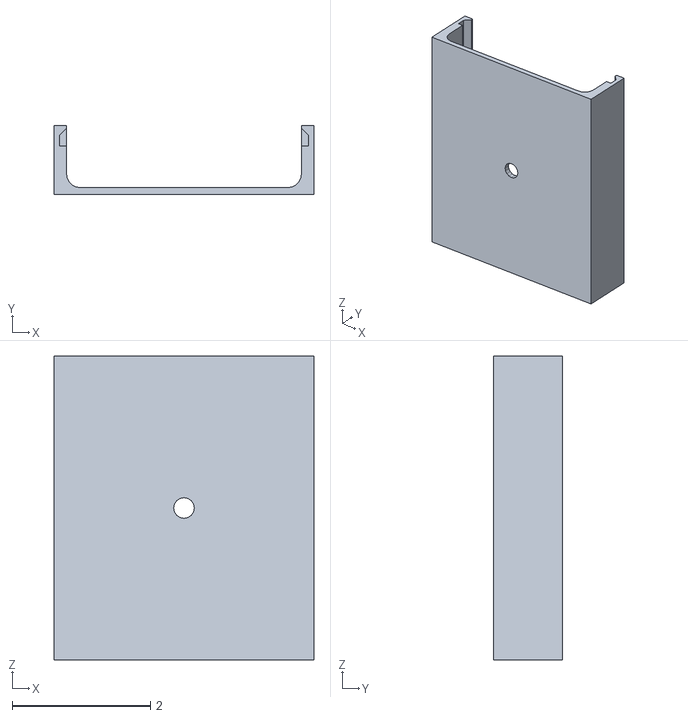
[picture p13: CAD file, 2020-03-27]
assets/cad/protection_circuit_holder/protection_circuit_holder.stl
3.76 x 1.00 x 4.40

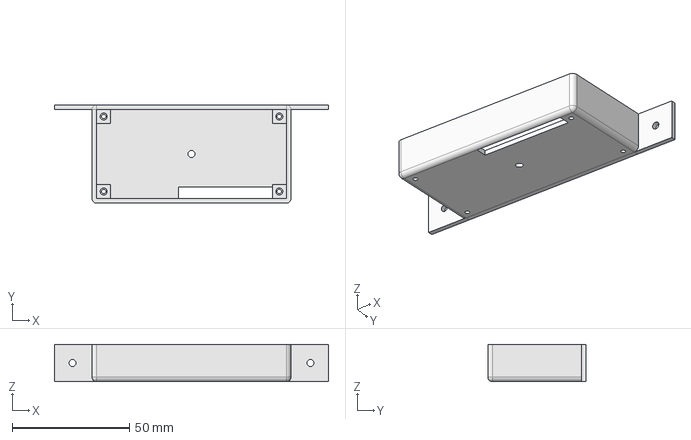
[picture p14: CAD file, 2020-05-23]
assets/cad/SC1602AWWB_holder/sc1602_socket.FCStd
117.0 x 42.0 x 16.0 mm

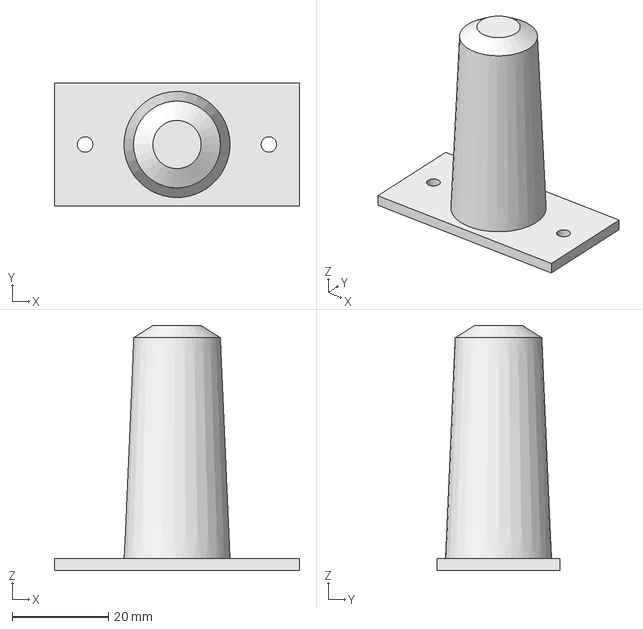
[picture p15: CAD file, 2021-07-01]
assets/cad/stick/stick.FCStd
50.8 x 25.4 x 50.8 mm

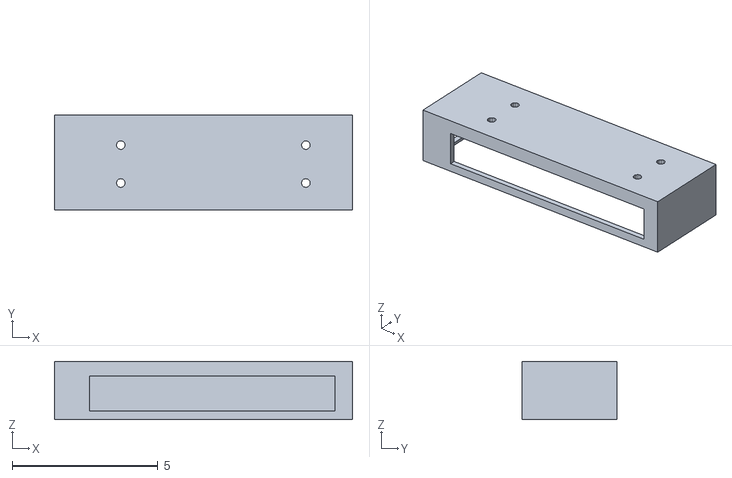
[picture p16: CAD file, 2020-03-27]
assets/cad/usb_hub_holder/usb_hub_holder.stl
10.2 x 3.25 x 2.00

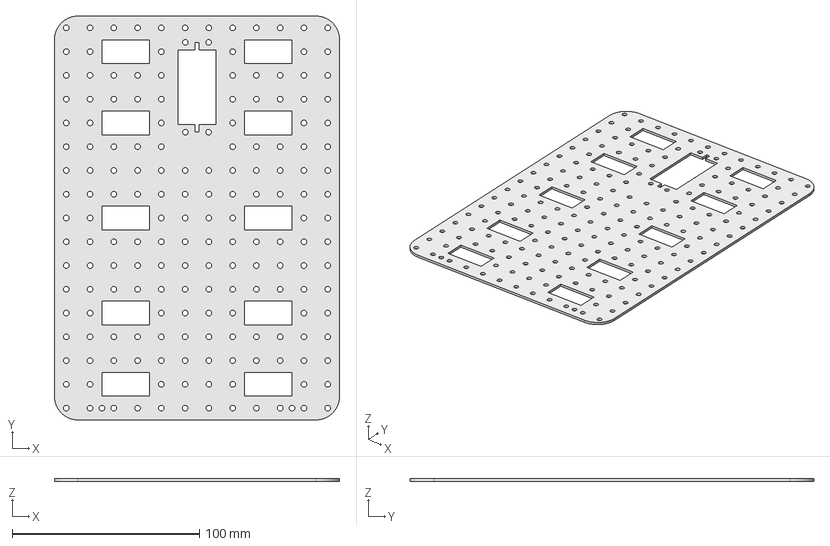
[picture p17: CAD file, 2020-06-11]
assets/cad/base_chassis/robocar_base.step
152.4 x 215.9 x 1.50 mm

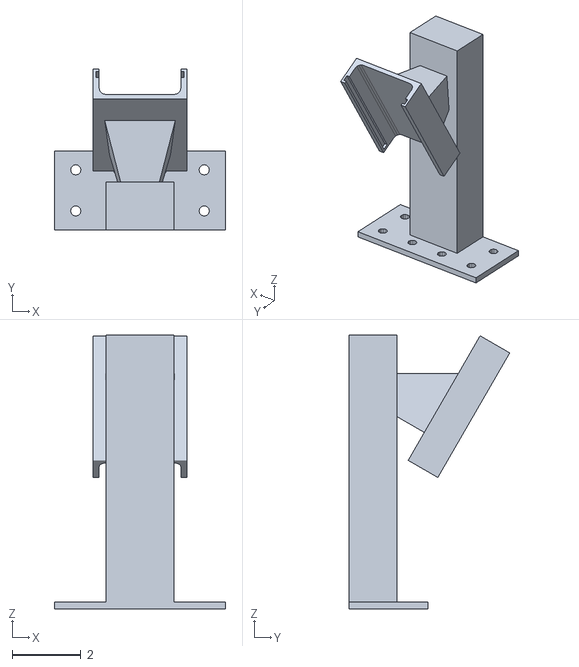
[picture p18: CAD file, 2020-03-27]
assets/cad/Pcam5C/Pcam5C_mounter.stl
5.00 x 4.69 x 8.00

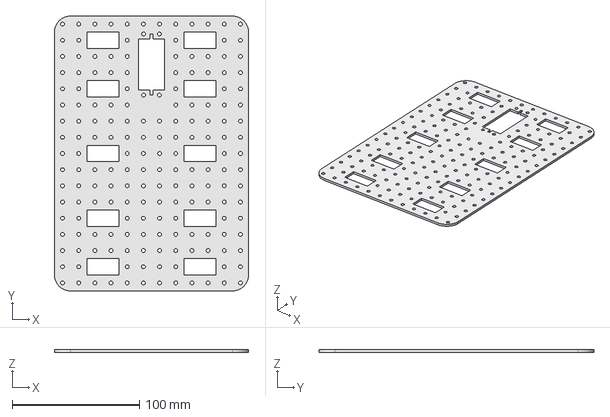
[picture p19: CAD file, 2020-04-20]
assets/cad/base_chassis/robocar_base2.step
152.4 x 215.9 x 2.00 mm

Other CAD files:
assets/cad/HB5_holder/HB5_holder.ipt
assets/cad/OLED_holder/OLED_holder.ipt
assets/cad/Pcam5C/Pcam5C_holder.ipt
assets/cad/Pcam5C/Pcam5C_mounter.ipt
assets/cad/SC1602AWWB_holder/sc1602_socket.stl
assets/cad/base_chassis/robocar_base.FCStd
assets/cad/base_chassis/robocar_base.stl
assets/cad/base_chassis/robocar_middle.FCStd
assets/cad/battery_case/battery_case.ipt
assets/cad/camera_cap_holder/camera_cap_holder.ipt
assets/cad/protection_circuit_holder/protection_circuit_holder.ipt
assets/cad/stick/stick.stl
assets/cad/usb_hub_holder/usb_hub_holder.ipt

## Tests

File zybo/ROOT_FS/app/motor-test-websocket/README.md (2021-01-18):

# motor-test-websocket

This example controls motors via Web browser.
It is assumed that host machine and ad-refkit are connected with WiFi.

## Install required libraries

```
$ sudo apt install python3-pip
$ sudo apt install python3-gevent
$ sudo apt install python3-websocket
$ sudo pip3 install websocket-server
```

## Prepare

```
$ mkdir build
$ cd build
$ cmake ..
$ make
$ cd ..
```

## Start server

```
$ cd python
$ sudo python3 -m http.server 8080 &
$ sudo python3 server.py
```

## Access via Web browser

Open http://IP-address-of-ad-refkit:8080/websocket_client.html by Web browser on your host PC.

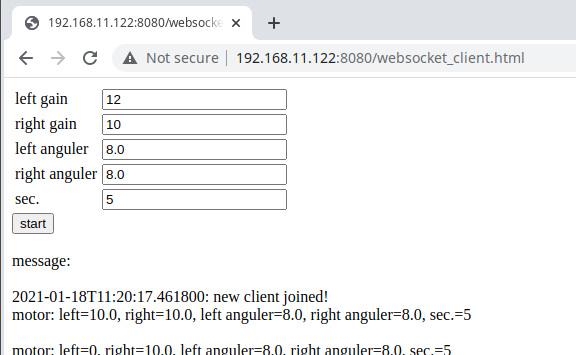
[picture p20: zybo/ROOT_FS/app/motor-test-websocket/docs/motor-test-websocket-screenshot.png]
motor-test-websocket-screenshot


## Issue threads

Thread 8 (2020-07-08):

Try to use USB WiFi adapter

miyo, 2020-07-08:
I'd like to use USB WiFi adapter to access ZYBO without wires. The candidates might be WDC-150SU2MBK or TL-WN725N

miyo, 2020-07-10:
I compiled Linux with the following config-file and installed a driver uploaded on https://github.com/lwfinger/rtl8188eu .
[dot.config.txt](https://github.com/fpga-design-contest/ad-refkit/files/4901016/dot.config.txt)
It is succeeded that the Zybo can use WiFi adapters.
I'll make a summary of the setup instruction.

miyo, 2020-07-10:
For USB WiFi adapter, documents and resources are updated at dc20be4f15588a15e30ca66de1eb796200e7225e

Closed 2020-07-10.

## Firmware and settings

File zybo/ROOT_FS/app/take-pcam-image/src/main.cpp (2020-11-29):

/**
 *  Take-pcam-image
 *
 *  Copyright (C) 2020 Takefumi Miyoshi.
 *  Authors:
 *      Takefumi Miyoshi <miyo@wasamon.net>
 *
 */

#include "main.h"
using namespace std;

void pcam_test() {

    std::cout << "take_pcam_image" << std::endl;

    zynqpl::PreImProc preimproc("uio4");
    preimproc.setGrayBinThreshold(224);
    preimproc.setHistThreshold(100, 80);
    preimproc.setSatBinThreshold(50);

    zynqpl::Pcam pcam("pcam0",
                      "i2c-0",
                      zynqpl::OV5640_cfg::mode_t::MODE_720P_1280_720_60fps,
                      zynqpl::OV5640_cfg::awb_t::AWB_ADVANCED,
                      V4L2_PIX_FMT_GREY);

    cv::Mat img(cv::Size(pcam.getImageWidth(), pcam.getImageHeight()), CV_8UC1);

    cv::namedWindow("frame buffer", cv::WINDOW_AUTOSIZE | cv::WINDOW_FREERATIO);

    std::cout << "s : Stop" << std::endl;
    std::cout << "w : write image" << std::endl;
    std::cout << "q : Quit" << std::endl;

    int           write_img_index = 0;
    bool          end_flag        = false;
    while(!end_flag) {
        pcam.fetchFrame(img.data);

        cv::imshow("frame buffer", img);
        auto key = cv::waitKey(100);
        switch(key) {
            case 's': {
                // s : Stop
                while(true) {
                    if(cv::waitKey(0)) {
                        break;
                    }
                }
                break;
            }
            case 'w': {
                // w : Write image
                cv::imwrite("img" + std::to_string(write_img_index) + ".png", img);
                write_img_index++;
                break;
            }
            case 'q': {
                // q : Quit
                end_flag = true;
                break;
            }
            default: {
                break;
            }
        }
    }
    cv::destroyAllWindows();
}

int main() {
    try {
        pcam_test();
    }
    catch(const std::exception& e) {
        std::cout << e.what() << std::endl;
    }
    catch(...) {
        std::cout << "An unexpected exception has occurred" << std::endl;
    }

    return 0;
}

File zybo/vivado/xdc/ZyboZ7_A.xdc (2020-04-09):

#Clock signal
#set_property -dict { PACKAGE_PIN K17   IOSTANDARD LVCMOS33 } [get_ports { sysclk }]; #IO_L12P_T1_MRCC_35 Sch=sysclk
#create_clock -add -name sys_clk_pin -period 8.00 -waveform {0 4} [get_ports { sysclk }];


#Switches
set_property -dict {PACKAGE_PIN G15 IOSTANDARD LVCMOS33} [get_ports {sw[0]}]
set_property -dict {PACKAGE_PIN P15 IOSTANDARD LVCMOS33} [get_ports {sw[1]}]
set_property -dict {PACKAGE_PIN W13 IOSTANDARD LVCMOS33} [get_ports {sw[2]}]
set_property -dict {PACKAGE_PIN T16 IOSTANDARD LVCMOS33} [get_ports {sw[3]}]


#Buttons
set_property -dict {PACKAGE_PIN K18 IOSTANDARD LVCMOS33} [get_ports {btn[0]}]
set_property -dict {PACKAGE_PIN P16 IOSTANDARD LVCMOS33} [get_ports {btn[1]}]
set_property -dict {PACKAGE_PIN K19 IOSTANDARD LVCMOS33} [get_ports {btn[2]}]
set_property -dict {PACKAGE_PIN Y16 IOSTANDARD LVCMOS33} [get_ports {btn[3]}]


#LEDs
set_property -dict {PACKAGE_PIN M14 IOSTANDARD LVCMOS33} [get_ports {led[0]}]
set_property -dict {PACKAGE_PIN M15 IOSTANDARD LVCMOS33} [get_ports {led[1]}]
set_property -dict {PACKAGE_PIN G14 IOSTANDARD LVCMOS33} [get_ports {led[2]}]
set_property -dict {PACKAGE_PIN D18 IOSTANDARD LVCMOS33} [get_ports {led[3]}]


#RGB LEDs
#set_property -dict { PACKAGE_PIN Y12   IOSTANDARD LVCMOS33 } [get_ports { led5_b }]; #IO_L20P_T3_13 Sch=led5_b
#set_property -dict { PACKAGE_PIN T5    IOSTANDARD LVCMOS33 } [get_ports { led5_g }]; #IO_L19P_T3_13 Sch=led5_g
#set_property -dict { PACKAGE_PIN Y11   IOSTANDARD LVCMOS33 } [get_ports { led5_r }]; #IO_L18N_T2_13 Sch=led5_r
#set_property -dict { PACKAGE_PIN M17   IOSTANDARD LVCMOS33 } [get_ports { led6_b }]; #IO_L8P_T1_AD10P_35 Sch=led6_b
#set_property -dict { PACKAGE_PIN F17   IOSTANDARD LVCMOS33 } [get_ports { led6_g }]; #IO_L6N_T0_VREF_35 Sch=led6_g
#set_property -dict { PACKAGE_PIN V16   IOSTANDARD LVCMOS33 } [get_ports { led6_r }]; #IO_L18P_T2_34 Sch=led6_r


#Audio Codec
#set_property -dict { PACKAGE_PIN R19   IOSTANDARD LVCMOS33 } [get_ports { ac_bclk }]; #IO_0_34 Sch=ac_bclk
#set_property -dict { PACKAGE_PIN R17   IOSTANDARD LVCMOS33 } [get_ports { ac_mclk }]; #IO_L19N_T3_VREF_34 Sch=ac_mclk
#set_property -dict { PACKAGE_PIN P18   IOSTANDARD LVCMOS33 } [get_ports { ac_muten }]; #IO_L23N_T3_34 Sch=ac_muten
#set_property -dict { PACKAGE_PIN R18   IOSTANDARD LVCMOS33 } [get_ports { ac_pbdat }]; #IO_L20N_T3_34 Sch=ac_pbdat
#set_property -dict { PACKAGE_PIN T19   IOSTANDARD LVCMOS33 } [get_ports { ac_pblrc }]; #IO_25_34 Sch=ac_pblrc
#set_property -dict { PACKAGE_PIN R16   IOSTANDARD LVCMOS33 } [get_ports { ac_recdat }]; #IO_L19P_T3_34 Sch=ac_recdat
#set_property -dict { PACKAGE_PIN Y18   IOSTANDARD LVCMOS33 } [get_ports { ac_reclrc }]; #IO_L17P_T2_34 Sch=ac_reclrc


#Audio Codec/external EEPROM IIC bus
#set_property -dict { PACKAGE_PIN N18   IOSTANDARD LVCMOS33 } [get_ports { ac_scl }]; #IO_L13P_T2_MRCC_34 Sch=ac_scl
#set_property -dict { PACKAGE_PIN N17   IOSTANDARD LVCMOS33 } [get_ports { ac_sda }]; #IO_L23P_T3_34 Sch=ac_sda


#Additional Ethernet signals
#set_property -dict { PACKAGE_PIN F16   IOSTANDARD LVCMOS33  PULLUP true    } [get_ports { eth_int_pu_b }]; #IO_L6P_T0_35 Sch=eth_int_pu_b
#set_property -dict { PACKAGE_PIN E17   IOSTANDARD LVCMOS33 } [get_ports { eth_rst_b }]; #IO_L3P_T0_DQS_AD1P_35 Sch=eth_rst_b


#Fan
#set_property -dict { PACKAGE_PIN Y13   IOSTANDARD LVCMOS33  PULLUP true    } [get_ports { fan_fb_pu }]; #IO_L20N_T3_13 Sch=fan_fb_pu


#HDMI RX
#set_property -dict { PACKAGE_PIN Y8    IOSTANDARD LVCMOS33 } [get_ports { hdmi_rx_cec }]; #IO_L14N_T2_SRCC_13 Sch=hdmi_rx_cec
#set_property -dict { PACKAGE_PIN U19   IOSTANDARD TMDS33     } [get_ports { hdmi_rx_clk_n }]; #IO_L12N_T1_MRCC_34 Sch=hdmi_rx_clk_n
#set_property -dict { PACKAGE_PIN U18   IOSTANDARD TMDS33     } [get_ports { hdmi_rx_clk_p }]; #IO_L12P_T1_MRCC_34 Sch=hdmi_rx_clk_p
#set_property -dict { PACKAGE_PIN W19   IOSTANDARD LVCMOS33 } [get_ports { hdmi_rx_hpd }]; #IO_L22N_T3_34 Sch=hdmi_rx_hpd
#set_property -dict { PACKAGE_PIN W18   IOSTANDARD LVCMOS33 } [get_ports { hdmi_rx_scl }]; #IO_L22P_T3_34 Sch=hdmi_rx_scl
#set_property -dict { PACKAGE_PIN Y19   IOSTANDARD LVCMOS33 } [get_ports { hdmi_rx_sda }]; #IO_L17N_T2_34 Sch=hdmi_rx_sda
#set_property -dict { PACKAGE_PIN W20   IOSTANDARD TMDS33     } [get_ports { hdmi_rx_n[0] }]; #IO_L16N_T2_34 Sch=hdmi_rx_n[0]
#set_property -dict { PACKAGE_PIN V20   IOSTANDARD TMDS33     } [get_ports { hdmi_rx_p[0] }]; #IO_L16P_T2_34 Sch=hdmi_rx_p[0]
#set_property -dict { PACKAGE_PIN U20   IOSTANDARD TMDS33     } [get_ports { hdmi_rx_n[1] }]; #IO_L15N_T2_DQS_34 Sch=hdmi_rx_n[1]
#set_property -dict { PACKAGE_PIN T20   IOSTANDARD TMDS33     } [get_ports { hdmi_rx_p[1] }]; #IO_L15P_T2_DQS_34 Sch=hdmi_rx_p[1]
#set_property -dict { PACKAGE_PIN P20   IOSTANDARD TMDS33     } [get_ports { hdmi_rx_n[2] }]; #IO_L14N_T2_SRCC_34 Sch=hdmi_rx_n[2]
#set_property -dict { PACKAGE_PIN N20   IOSTANDARD TMDS33     } [get_ports { hdmi_rx_p[2] }]; #IO_L14P_T2_SRCC_34 Sch=hdmi_rx_p[2]
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

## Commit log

2020-03-27 add 3DCAD data
    [HB5_holder.ipt, HB5_holder.stl, OLED_holder.ipt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]
2020-03-27 add v4l2 driver
2020-03-27 add an application to execute camera calibration using OpenCV
2020-03-27 add an application to test motors
2020-03-28 update make-calibration-param
2020-03-28 update motor-test
2020-03-31 add i2c-overlay to access PCAM5C registers
2020-04-05 add ad-sample
    [motor.yaml]
2020-04-06 added APIs to read buttons. ad-sample works
2020-04-06 bugfix interrupt id for v4l2
2020-04-07 update create_prj.tcl to add buttons, and modify the compilation flow to run automatically.
2020-04-07 to use DeviceParam to get device file for buttons in ad_sample
2020-04-08 bugfix: Wheel Odometry update calculation
    [Handler.cpp]
2020-04-09 add a controller for I2C OLED module to display some debug info.
2020-04-12 add updating motor control values
2020-04-20 sec1 in english
    [robocar_base.stl]
2020-04-20 add requires verilog files for i2c-OLED module into create_prj.tcl
2020-05-23 added freecad and gcode for a SC1602AWWB holder
    [sc1602_socket.FCStd, sc1602_socket.stl]
2020-06-01 add enable-flag for Web-Camera
2020-06-11 update chassis cad data
    [robocar_base.FCStd, robocar_base.step, robocar_base.stl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]
2020-06-29 modified i2c-OLED connections
2020-11-27 add v4l2 driver patch
2020-11-29 add take-pcam-image to take pictures for make-calibration-param
2021-01-18 motor-test-websocket, control motors via Web browser
2021-02-24 add detals of calibration in sec5/index.md
2021-06-30 add stick
    [stick.FCStd, stick.stl]
